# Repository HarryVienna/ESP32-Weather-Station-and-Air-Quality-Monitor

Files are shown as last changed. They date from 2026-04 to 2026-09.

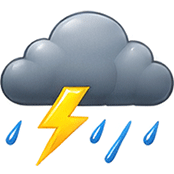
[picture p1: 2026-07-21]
EEZ-Studio-1280x800/images/night_95.png

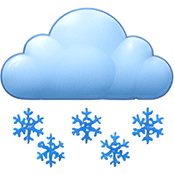
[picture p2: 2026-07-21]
EEZ-Studio-1280x800/images/night_75.png

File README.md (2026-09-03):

# ESP32 Weather Station, Indoor Air Quality & Radiation Monitor

A DIY weather station built from several cooperating ESP32/CubeCell devices: a touchscreen base
station that displays everything, a dedicated radio gateway, and a family of battery-powered
wireless sensor nodes (temperature/humidity, barometric pressure, and radiation) spread around a
house and garden.

🔗 **Read the full story and build log:** [Harald Kreuzer's Blog](https://www.haraldkreuzer.net/en/news/build-guide-esp32-weather-station-and-environmental-monitor)

DSC_2189_mittel

## Overview

The system is split into three tiers:

1. **[`BaseStation/`](BaseStation/README.md)** — an ESP32-P4 with a 10.1" DSI touchscreen. The only
   part you actually interact with: it shows live sensor readings, 24h history charts, a weather
   forecast pulled from the internet, and lets you configure WiFi/location/sensor icons entirely
   from the touchscreen. It also carries its own built-in air quality sensor (SEN66).
2. **[`Sensor-Receiver/`](Sensor-Receiver/)** — an ESP32-S3 that acts as a radio gateway. It listens
   for both LoRa and ESP-NOW packets from the wireless sensor nodes, buffers them, and exposes them
   to the base station over an I2C slave interface. It has its own small OLED status display.
3. **Wireless sensor nodes** — several independent, battery-powered firmwares (see the table below),
   each reading one physical sensor and periodically transmitting a small packet over LoRa or
   ESP-NOW before going back to sleep.

```
 Wireless sensor nodes  --LoRa/ESP-NOW-->  Sensor-Receiver  --I2C-->  BaseStation  <--HTTPS-->  Weather API
 (battery, deep sleep)                     (ESP32-S3)                (ESP32-P4 +
                                                                       touchscreen)
```

## Components

| Folder | Board | Framework | Sensor | Radio | Role |
|---|---|---|---|---|---|
| [`BaseStation`](BaseStation/README.md) | Waveshare ESP32-P4-Module-DEV-KIT | ESP-IDF | SEN66 (built-in) | — | Display, GUI, weather fetch |
| [`Sensor-Receiver`](Sensor-Receiver/) | Heltec WiFi LoRa 32 (ESP32-S3) | ESP-IDF | — | LoRa + ESP-NOW (receiver) | Radio gateway to BaseStation (I2C) |
| [`Sensor-LORA-BME280`](Sensor-LORA-BME280/) | Heltec WiFi LoRa 32 V3/V4 (ESP32-S3) | ESP-IDF | BME280 | LoRa | Temperature/humidity/pressure node |
| [`Sensor-LORA-BME280-HTCC-AB01`](Sensor-LORA-BME280-HTCC-AB01/) | Heltec CubeCell HTCC-AB01 V2 | PlatformIO/Arduino | BME280 | LoRa | Same as above, tiny low-power board |
| [`Sensor-LORA-SHT45`](Sensor-LORA-SHT45/) | Heltec WiFi LoRa 32 V3/V4 (ESP32-S3) | ESP-IDF | SHT45 | LoRa | Temperature/humidity node (no pressure) |
| [`Sensor-LORA-RadiationD`](Sensor-LORA-RadiationD/) | Heltec WiFi LoRa 32 V4 (ESP32-S3) | ESP-IDF | RadiationD-v1.1 Geiger tube | LoRa | Geiger counter node, ULP pulse counting |
| [`Sensor-LORA-RadiationD-HTCC-AB01`](Sensor-LORA-RadiationD-HTCC-AB01/) | Heltec CubeCell HTCC-AB01 V2 | PlatformIO/Arduino | RadiationD-v1.1 Geiger tube | LoRa | Same as above, tiny low-power board |
| [`Sensor-ESP-NOW-BME280`](Sensor-ESP-NOW-BME280/) | generic ESP32 | ESP-IDF | BME280 | ESP-NOW | Temperature/humidity/pressure node (the original, oldest project here) |
| [`EEZ-Studio-1280x800`](EEZ-Studio-1280x800/) | — | [EEZ Studio](https://github.com/eez-open/studio) project | — | — | Design-time source for BaseStation's LVGL touchscreen GUI |

Every LoRa node uses the same link parameters (869.525 MHz, BW125, CR 4/5, sync word `0x1424`), so
the ESP32-based and CubeCell-based variants of the same sensor are interchangeable from
`Sensor-Receiver`'s point of view — it doesn't know or care which MCU sent a packet.

## Shared wire protocol

All sensor nodes and `Sensor-Receiver` share a single `common/packet_format.h` (copied into each
firmware, byte-for-byte identical) that defines the over-the-air packet layout:

- **`message_type_t`** — `PAIRING_REQ` (0), `PAIRING_RESP` (1), `DATA` (2). Pairing is only used on
  the ESP-NOW side, to let a sensor learn the receiver's MAC address/channel on first boot (and
  re-pair automatically if a send ever fails).
- **`sensor_type_t`** — `SENSOR_TYPE_BME280` (1), `SENSOR_TYPE_SHT45` (2), `SENSOR_TYPE_GEIGER` (3),
  `SENSOR_TYPE_CUSTOM` (255).
- **`packet_header_t`** (4 bytes, packed) — `msg_type`, `sensor_nr` (which of the 6 slots this
  sensor occupies), `sensor_type`, `payload_len`.
- **`link_metadata_t`** (11 bytes) — `msg_source` (LoRa/ESP-NOW), `rssi`, `snr`, `timestamp`. Added
  by `Sensor-Receiver` itself; never transmitted over the air.
- One payload struct per sensor type (`bme280_payload_t`, `sht45_payload_t`, `geiger_payload_t`),
  each carrying the measurement plus the sending node's battery voltage.

`BaseStation` reads the same header to know which of its 6 sensor-card slots a packet belongs to
and which struct to cast the payload to.

## Power management

Every wireless node spends nearly all of its life in deep sleep and wakes only to measure and
transmit:

- Temperature/humidity/pressure nodes wake every **10 minutes**, take one reading, transmit, and go
  back to sleep.
- Geiger counter nodes need to accumulate pulses over time rather than take a single instant
  reading, so they wake more often (every 60s on the ESP32 variant, with a rolling average kept in
  RTC memory across wakeups) and keep counting through sleep: the ESP32-based sensor runs a small
  ULP (co-processor) program that counts Geiger pulses even while the main CPU is powered down, so
  no pulses are lost between wakeups. It also uses dynamic CPU frequency scaling and gates the LoRa
  power amplifier on only for the moment of transmission — an iterative optimization that brought
  its average current down from roughly 45 mA to under 30 mA.
- Before sleeping, every ESP32-based node explicitly isolates the radio's SPI pins, the OLED's power
  rail, and unused UART pins to avoid leakage current through them.
- The CubeCell-based nodes (`*-HTCC-AB01`) use the ASR6502's native low-power timer/interrupt
  wake instead of ESP32 deep sleep, since that board has no equivalent RTC/ULP domain.

## Getting started

Each folder is an independent firmware project — `BaseStation`, `Sensor-Receiver` and the ESP32-based
sensor nodes are ESP-IDF projects (`idf.py build`/`flash`); the two `*-HTCC-AB01` nodes are
PlatformIO/Arduino projects (`pio run --target upload`). See
**[`BaseStation/README.md`](BaseStation/README.md)** for the full build/flash walkthrough of the
main display unit, which is the best starting point if you just want to see the system running.

## License

[GPL-3.0](LICENSE)

## Acknowledgments

- [EEZ Studio](https://github.com/eez-open/studio) for the GUI editor/code generator
- [LVGL](https://lvgl.io/) as the graphics library
- Espressif for ESP-IDF and the `esp_lvgl_port`/`esp_lcd_*` driver components
- Heltec for the WiFi LoRa 32 and CubeCell hardware/BSPs

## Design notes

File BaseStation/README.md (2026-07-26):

# ESP32 Weather Station & Indoor Air Quality Monitor — Base Station

*[Deutsch](README_de.md)*

A base station built around the **ESP32-P4** with a 10.1" touchscreen that brings together weather
data from the internet, a built-in air quality sensor, and up to six battery-powered wireless sensors
(LoRa / ESP-NOW) — including a Geiger counter — on a single display.

> This is one component of a larger project — see the
> [repository root README](../README.md) for the full system overview and a photo of the hardware.

## Overview

The overall system consists of three parts:

1. **This base station** (ESP32-P4 + touchscreen) — displays all the data and is the only part you
   actually interact with.
2. A **Sensor Receiver** (ESP32-S3) that collects LoRa and ESP-NOW packets from the wireless sensors
   in the background and forwards them to the base station over I2C.
3. Several **battery-powered wireless sensors** (temperature/humidity, some with barometric pressure,
   plus a Geiger counter), which spend most of their time in deep sleep and only transmit
   periodically.

The base station itself also has a built-in **SEN66** sensor (particulate matter, VOC, NOx, CO₂,
temperature, humidity) and fetches the weather forecast from the internet over WiFi.

## Features

- Live display of all connected sensors (up to 6 wireless sensors + the built-in SEN66)
- 24h history charts with peak bucketing — short spikes (e.g. a brief rise in particulate matter)
  stay visible in the chart instead of disappearing into an average
- Color-coded thresholds for battery voltage, signal strength, particulate matter, VOC, NOx, CO₂ and
  radiation
- Weather forecast from three selectable providers (Open-Meteo, OpenWeatherMap, VisualCrossing) with
  hourly and daily charts
- Geiger counter integration, including its own radiation color scale and 24h history
- Automatic display brightness based on ambient light and presence sensing
- Fully configurable from the touchscreen (WiFi, location/timezone, sensor icons) — no reflashing
  needed for basic setup
- Per-slot offline watchdog: a sensor card's header turns red once that sensor hasn't reported in for
  a while

## Hardware

| Component | Part |
|---|---|
| Board | Waveshare ESP32-P4-Module-DEV-KIT |
| Display | Waveshare 10.1" DSI touch (800×1280, run in 1280×800 landscape) |
| Touch controller | GT911 (capacitive) |
| Built-in air quality sensor | Sensirion SEN66 |
| Ambient light sensor | BH1750 |
| Presence sensor | C4001 (mmWave radar) |
| WiFi | routed through an ESP32-C6 co-processor via esp-hosted (the P4 has no native WiFi radio) |
| Wireless counterpart | Sensor Receiver (ESP32-S3), receives LoRa (SX1262) + ESP-NOW and forwards over I2C |

## Project layout

```
main/
├── main.c              Boot sequence (app_main)
├── config/             Color palette, WiFi/I2C constants
├── display/             DSI panel, backlight, touch
├── i2c/                Shared I2C bus
├── receiver/           I2C polling from the Sensor Receiver, offline watchdog
├── wifi/               WiFi connection, NTP time sync
├── nvs/                Configuration stored in flash
├── weather/            Weather providers (Open-Meteo/OpenWeatherMap/VisualCrossing)
├── lvgl/               Custom LVGL chart widgets (hourly/daily chart)
├── ui/                 Screens generated by EEZ Studio (do not edit by hand)
└── gui/
    ├── sensors/        SEN66 and wireless-sensor display, color scales, 24h charts
    ├── setup/          Setup screen (WiFi, form, keyboard wiring)
    ├── weatherstation/ Starts the background tasks when the main screen loads
    ├── weather/        Weather display
    └── status/         WiFi icon, clock, brightness
```

## Getting started

Requires **ESP-IDF v5.5.4** (other 5.5.x versions are likely compatible but untested).

```powershell
git clone <repo-url>
cd BaseStation
idf.py set-target esp32p4
idf.py build
idf.py -p COMx flash monitor
```

On first boot, the base station shows the setup screen: pick a WiFi network, enter
location/timezone, choose a weather provider (+ API key if needed), and assign an icon to each of
the 6 sensor slots. Everything is stored in NVS and survives a reboot.

> **Note:** `main.c` contains an additional, hardcoded WiFi connection attempt at boot. It exists
> solely for the automatic screenshot task used during development (see `start_screenshot()`) — it's
> not needed for normal operation, since the actual WiFi setup happens through the setup screen.

## Related projects

Part of the same weather station, but with their own firmware/repository:

- **Sensor-Receiver** — ESP32-S3, receives LoRa + ESP-NOW and exposes the data to the base station over I2C
- **Sensor-LORA-BME280** / **Sensor-LORA-SHT45** / **Sensor-LORA-RadiationD** — battery-powered LoRa wireless sensors
- **Sensor-ESP-NOW-BME280** — wireless sensor over ESP-NOW instead of LoRa

## License

[GPL-3.0](LICENSE)

## Acknowledgments

- [EEZ Studio](https://github.com/eez-open/studio) for the GUI editor/code generator
- [LVGL](https://lvgl.io/) as the graphics library
- Espressif for ESP-IDF and the `esp_lvgl_port`/`esp_lcd_*` driver components

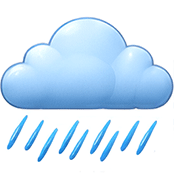
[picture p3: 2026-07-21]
EEZ-Studio-1280x800/images/night_65.png

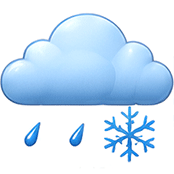
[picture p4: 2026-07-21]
EEZ-Studio-1280x800/images/night_56.png

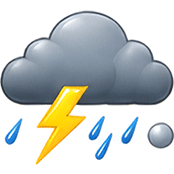
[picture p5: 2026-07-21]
EEZ-Studio-1280x800/images/night_96.png

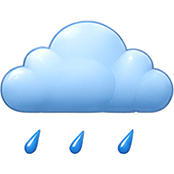
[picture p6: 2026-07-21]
EEZ-Studio-1280x800/images/night_51.png

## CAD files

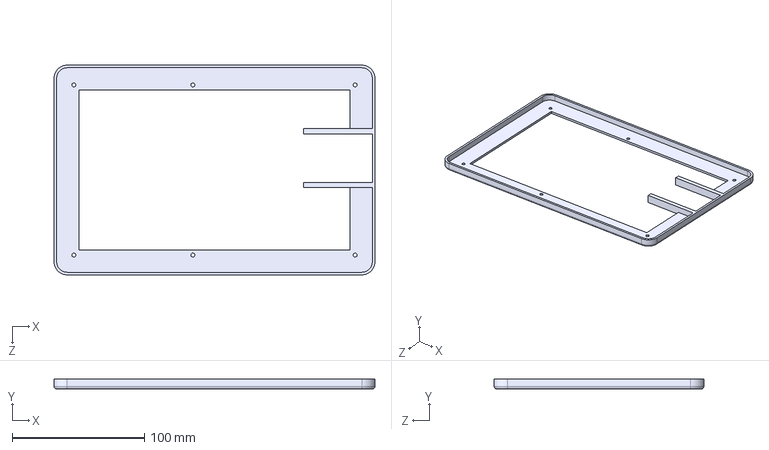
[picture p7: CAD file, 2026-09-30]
SolidWorks/Gehäuse_Guition_Rückwand_Rand.STEP
242.8 x 7.50 x 158.7 mm

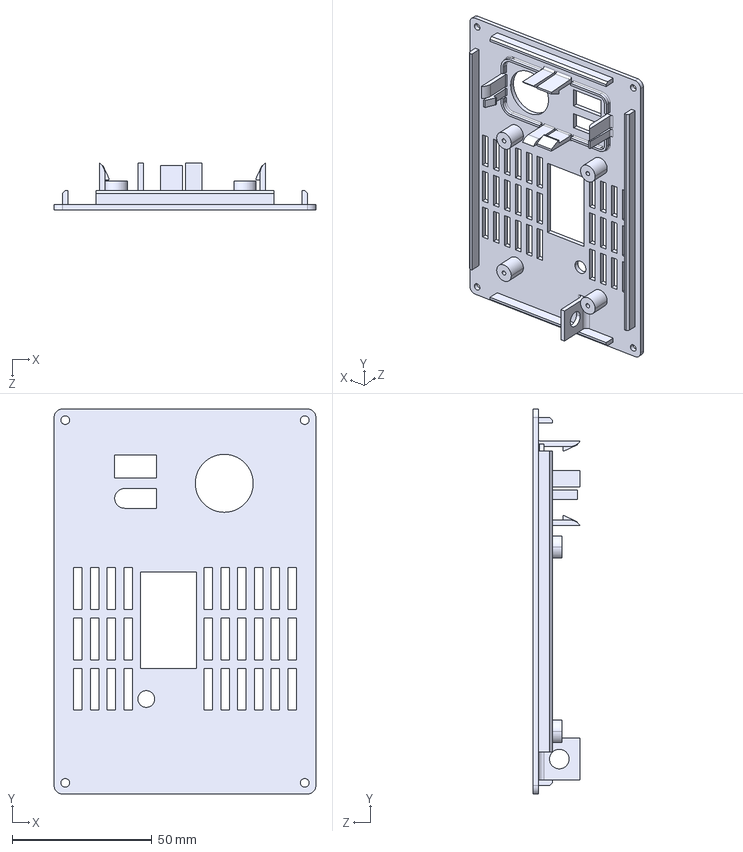
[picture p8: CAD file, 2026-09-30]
SolidWorks/Gehäuse_Guition_Deckel.STEP
93.7 x 137.8 x 17.0 mm

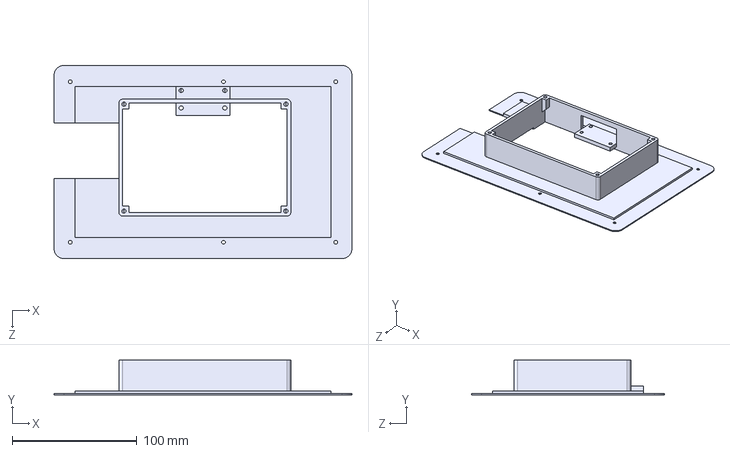
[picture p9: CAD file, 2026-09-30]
SolidWorks/Gehäuse_Guition_Rückwand_Haupt.STEP
238.8 x 28.0 x 154.7 mm

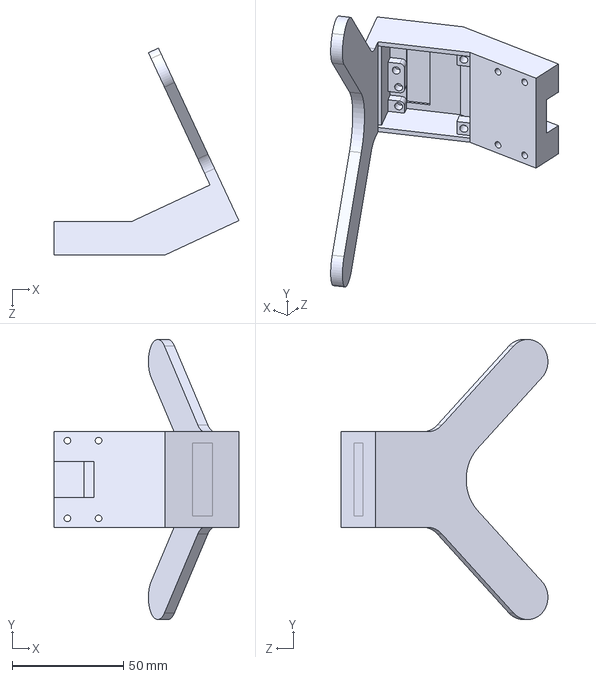
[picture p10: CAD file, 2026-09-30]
SolidWorks/Gehäuse_Guition_Sockel.STEP
83.2 x 126.0 x 93.1 mm

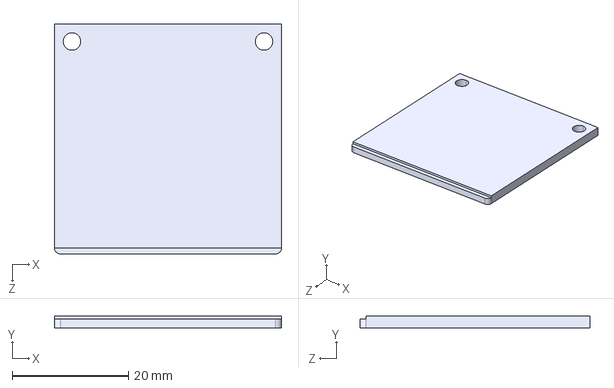
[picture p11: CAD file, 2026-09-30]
SolidWorks/Gehäuse_Guition_Abdeckung.STEP
39.0 x 2.00 x 39.5 mm

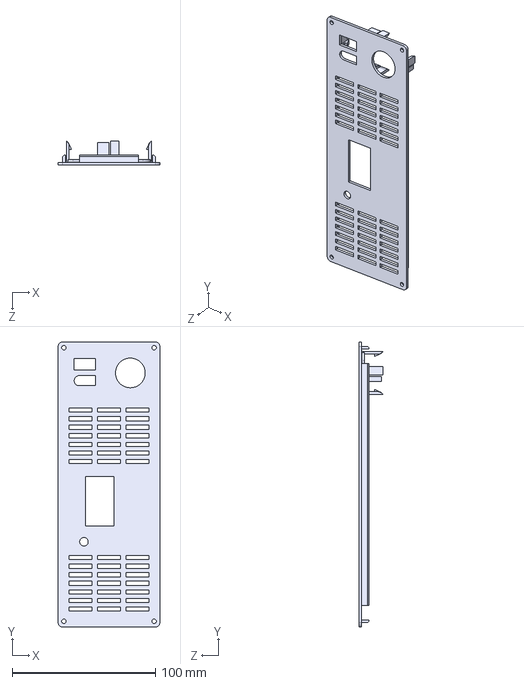
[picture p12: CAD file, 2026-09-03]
SolidWorks/Gehäuse_Waveshare_Deckel.STEP
71.0 x 199.0 x 17.0 mm

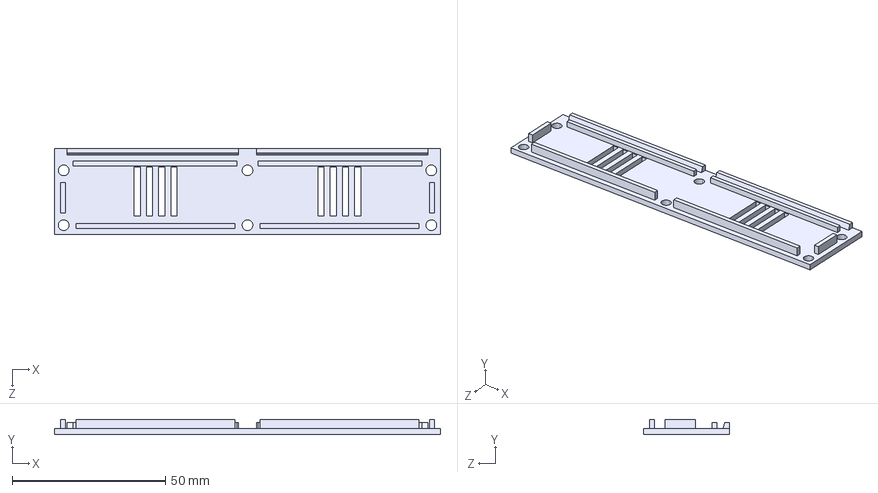
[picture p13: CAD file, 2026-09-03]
SolidWorks/Sensor_Halterung_ESP-NOW_2_Panel_Deckel.STEP
126.0 x 5.00 x 28.0 mm

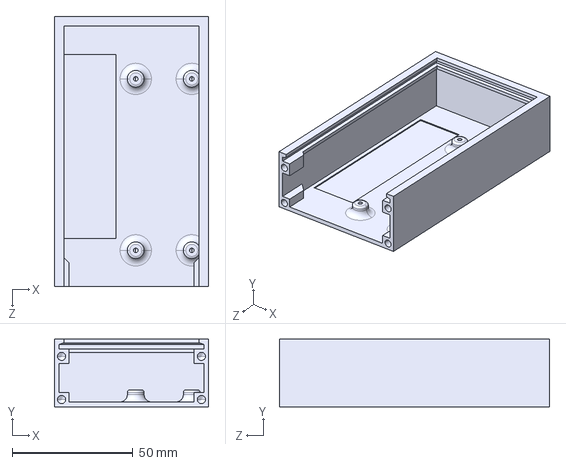
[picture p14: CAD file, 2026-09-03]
SolidWorks/Sensor_Halterung_ESP-NOW_1_Panel.STEP
64.0 x 28.0 x 112.0 mm

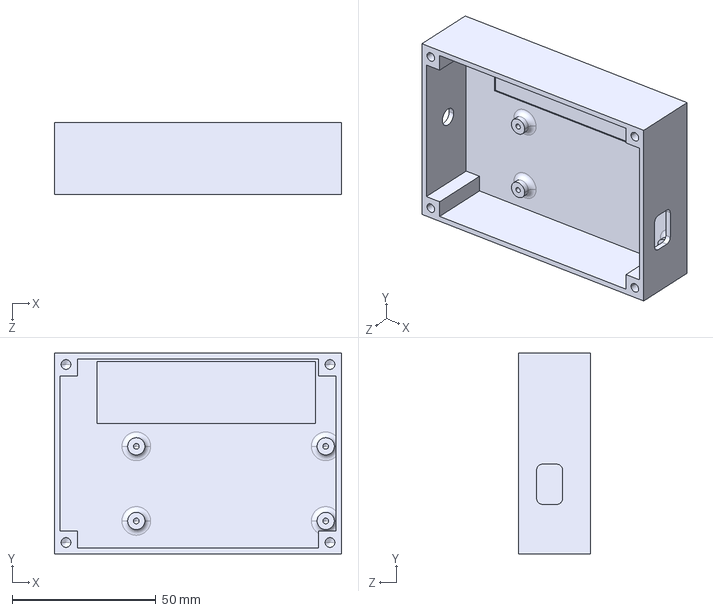
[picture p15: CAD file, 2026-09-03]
SolidWorks/Sensor_Halterung_LoRa.STEP
100.0 x 70.0 x 25.0 mm

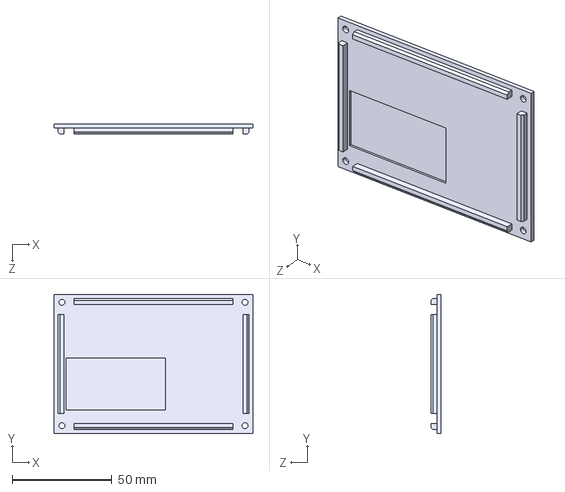
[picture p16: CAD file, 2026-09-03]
SolidWorks/Sensor_Halterung_LoRa_Deckel.STEP
100.0 x 70.0 x 5.00 mm

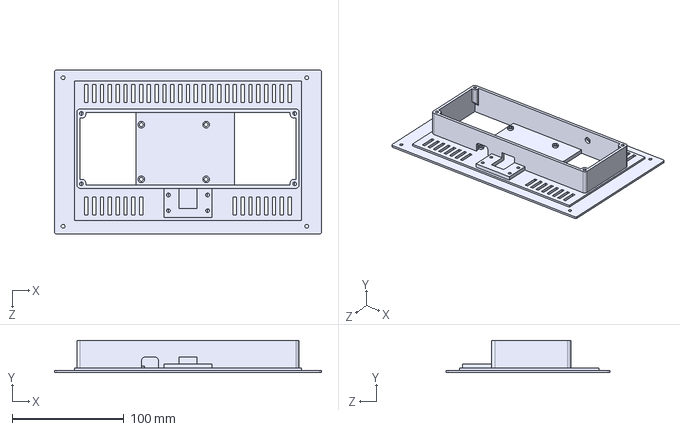
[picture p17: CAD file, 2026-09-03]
SolidWorks/Gehäuse_Waveshare_Rückwand_Haupt.STEP
239.0 x 29.0 x 147.0 mm

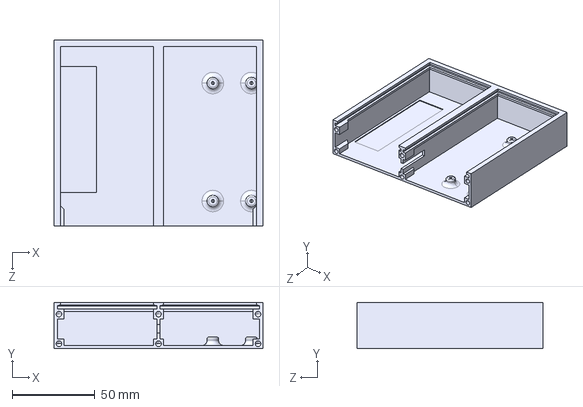
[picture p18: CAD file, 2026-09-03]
SolidWorks/Sensor_Halterung_ESP-NOW_2_Panel.STEP
126.0 x 28.0 x 112.0 mm

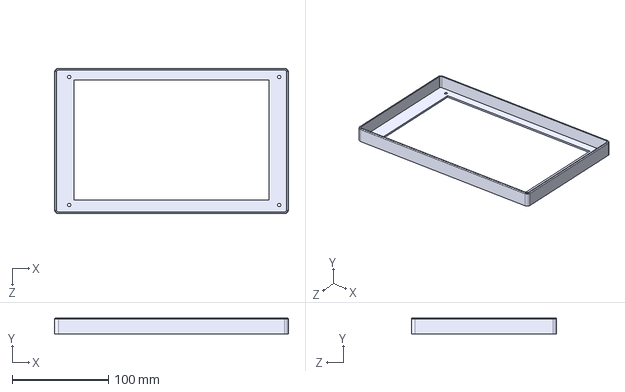
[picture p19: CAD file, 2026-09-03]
SolidWorks/Gehäuse_Waveshare_Rückwand_Rand.STEP
243.0 x 16.5 x 151.0 mm

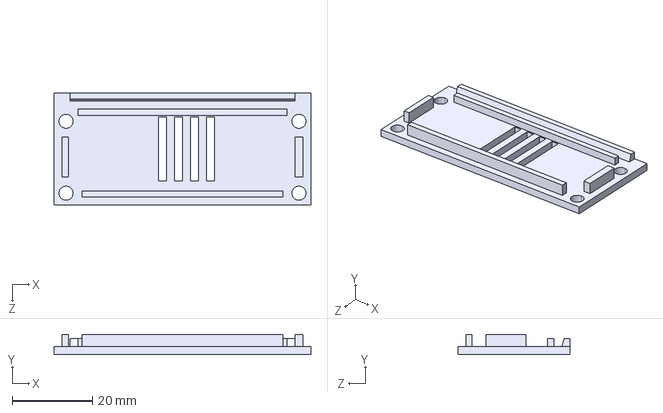
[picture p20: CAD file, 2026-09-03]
SolidWorks/Sensor_Halterung_ESP-NOW_1_Panel_Deckel.STEP
64.0 x 5.00 x 28.0 mm

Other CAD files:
SolidWorks/Gehäuse_Waveshare_Sockel_Deckel.STEP
SolidWorks/Gehäuse_Waveshare_Sockel.STEP
SolidWorks/Gehäuse_Guition_Abdeckung.SLDPRT
SolidWorks/Gehäuse_Guition_Deckel.SLDPRT
SolidWorks/Gehäuse_Guition_Rückwand_Haupt.SLDPRT
SolidWorks/Gehäuse_Guition_Rückwand_Rand.SLDPRT
SolidWorks/Gehäuse_Guition_Sockel.SLDPRT
SolidWorks/Gehäuse_Waveshare_Deckel.SLDPRT
SolidWorks/Gehäuse_Waveshare_Rückwand_Haupt.SLDPRT
SolidWorks/Gehäuse_Waveshare_Rückwand_Rand.SLDPRT
SolidWorks/Gehäuse_Waveshare_Sockel.SLDPRT
SolidWorks/Gehäuse_Waveshare_Sockel_Deckel.SLDPRT
SolidWorks/Sensor_Halterung_ESP-NOW_1_Panel.SLDPRT
SolidWorks/Sensor_Halterung_ESP-NOW_1_Panel_Deckel.SLDPRT
SolidWorks/Sensor_Halterung_ESP-NOW_2_Panel.SLDPRT
SolidWorks/Sensor_Halterung_ESP-NOW_2_Panel_Deckel.SLDPRT
SolidWorks/Sensor_Halterung_LoRa.SLDPRT
SolidWorks/Sensor_Halterung_LoRa_Deckel.SLDPRT

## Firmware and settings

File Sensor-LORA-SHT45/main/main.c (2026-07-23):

/**
 * @file main.c
 * @brief LoRa Sensor Sender — Heltec WiFi LoRa 32 V3 (ESP32-S3 / SX1262)
 *
 * Boot paths:
 *   Reset → config menu on OLED → measure → send → (deep sleep)
 *   Deep sleep wake → load config from NVS → measure → send → (deep sleep)
 */

#include <stdio.h>
#include <string.h>

#include "freertos/FreeRTOS.h"
#include "freertos/task.h"

#include "driver/gpio.h"

#include "esp_adc/adc_oneshot.h"
#include "esp_adc/adc_cali.h"
#include "esp_adc/adc_cali_scheme.h"

#include "esp_sleep.h"
#include "esp_log.h"
#include "nvs_flash.h"

#include "driver/i2c_master.h"

#include "u8g2_esp32_hal.h"
#include "sx1262.h"
#include "sensirion_i2c_hal.h"
#include "sht4x_i2c.h"

#include "../common/packet_format.h"
#include "config.h"

/* ============================================================================
 * Constants
 * ============================================================================ */

#define SLEEP_TIME_SECONDS 600

/* LED */
#define PIN_LED      GPIO_NUM_35

/* Heltec V4 FEM / power pins */
#define PIN_VEXT     GPIO_NUM_36  // Display power (LOW = on)
// #define PIN_VFEM     GPIO_NUM_7   // Amplifier power (HIGH = on)
// #define PIN_PA_CSD   GPIO_NUM_2   // GC1109 chip shutdown (HIGH = enabled)
// #define PIN_PA_CPS   GPIO_NUM_46  // GC1109 RX/TX path (HIGH = high-power TX)

/* Display (SSD1306 128x64) */
#define DISPLAY_SDA  GPIO_NUM_17
#define DISPLAY_SCL  GPIO_NUM_18
#define DISPLAY_RST  GPIO_NUM_21

/* ADC — GPIO37 = ADC_CTRL (HIGH enables voltage divider)
 *         GPIO1  = VBAT_Read = ADC1_CH0
 *         Divider: 390k : 100k = 4.9×                      */
#define ADC_CTRL       GPIO_NUM_37
#define ADC_CHANNEL    ADC_CHANNEL_0
#define ADC_UNIT       ADC_UNIT_1
#define ADC_ATTEN      ADC_ATTEN_DB_2_5
#define ADC_VBAT_R1    390.0f
#define ADC_VBAT_R2    100.0f
#define ADC_VBAT_CALIB (4140.0f / 4037.0f)    // empirical correction (avg 4037 mV, multimeter 4140 mV)
#define ADC_SAMPLES    16                      // average N readings to reduce noise

/* SHT45 I2C bus */
#define I2C_SDA     GPIO_NUM_48
#define I2C_SCL     GPIO_NUM_47

/* UART */
#define UART0_RXD     GPIO_NUM_44
#define UART0_TXD     GPIO_NUM_43

/* LoRa (SX1262 / GC1109) — settings that never change */
#define LORA_FREQUENCY        869525000UL  // 869.525 MHz — G3 band centre
#define LORA_BANDWIDTH        LORA_BW_125
#define LORA_CODING_RATE      LORA_CR_4_5
#define LORA_PREAMBLE_LENGTH  8
#define LORA_PAYLOAD_LENGTH   0
#define LORA_CRC_ON           true
#define LORA_IQ_INVERTED      true
#define LORA_RX_GAIN_BOOSTED  true
#define LORA_SYNC_WORD        0x1424

static const char *TAG = "main";

/* ============================================================================
 * LED
 * ============================================================================ */

static void blink(void) {
    gpio_config_t led_conf = {
        .pin_bit_mask = (1ULL << PIN_LED),
        .mode = GPIO_MODE_OUTPUT,
        .pull_up_en = GPIO_PULLUP_DISABLE,
        .pull_down_en = GPIO_PULLDOWN_DISABLE,
        .intr_type = GPIO_INTR_DISABLE,
    };
    gpio_config(&led_conf);
    gpio_set_level(PIN_LED, 1);
    vTaskDelay(pdMS_TO_TICKS(10));
    gpio_set_level(PIN_LED, 0);
}

/* ============================================================================
 * Board init
 * ============================================================================ */

/**
 * Configure Heltec V3 FEM and optionally the display power rail.
 * Pass enable_display=false on deep-sleep wake to skip VEXT.
 */
static esp_err_t init_heltec_v3(bool enable_display) {
    // Release deep sleep IO hold (no-op on first boot)
    gpio_deep_sleep_hold_dis();

    // FEM pins
    // gpio_config_t io_conf = {
    //     .pin_bit_mask = (1ULL << PIN_VFEM | 1ULL << PIN_PA_CSD | 1ULL << PIN_PA_CPS),
    //     .mode = GPIO_MODE_OUTPUT,
    //     .pull_up_en = GPIO_PULLUP_DISABLE,
    //     .pull_down_en = GPIO_PULLDOWN_DISABLE,
    //     .intr_type = GPIO_INTR_DISABLE,
    // };
    // gpio_config(&io_conf);
    // gpio_set_level(PIN_PA_CSD, 1);
    // gpio_set_level(PIN_PA_CPS, 1);
    // gpio_set_level(PIN_VFEM,   1);

    // VEXT: only on when display is needed (SHT45 runs on permanent 3.3V)
    gpio_config_t vext_conf = {
        .pin_bit_mask = (1ULL << PIN_VEXT),
        .mode = GPIO_MODE_OUTPUT,
        .pull_up_en = GPIO_PULLUP_DISABLE,
        .pull_down_en = GPIO_PULLDOWN_DISABLE,
        .intr_type = GPIO_INTR_DISABLE,
    };
    gpio_config(&vext_conf);
    gpio_set_level(PIN_VEXT, enable_display ? 0 : 1);

    if (enable_display) {
        vTaskDelay(pdMS_TO_TICKS(200));   // VEXT rail stabilisation
    }

    ESP_LOGI(TAG, "Heltec V3 init (display=%s)", enable_display ? "on" : "off");
    return ESP_OK;
}

/* ============================================================================
 * Display
 * ============================================================================ */

static esp_err_t init_display(u8g2_t *u8g2) {
    u8g2_esp32_hal_t hal = U8G2_ESP32_HAL_DEFAULT;
    hal.bus.i2c.sda = DISPLAY_SDA;
    hal.bus.i2c.scl = DISPLAY_SCL;
    hal.reset        = DISPLAY_RST;
    u8g2_esp32_hal_init(hal);

    vTaskDelay(pdMS_TO_TICKS(100));

    u8g2_Setup_ssd1306_i2c_128x64_noname_f(
        u8g2, U8G2_R0,
        u8g2_esp32_i2c_byte_cb,
        u8g2_esp32_gpio_and_delay_cb);
    u8x8_SetI2CAddress(&u8g2->u8x8, 0x3C << 1);

    u8g2_InitDisplay(u8g2);
    u8g2_SetPowerSave(u8g2, 0);

    ESP_LOGI(TAG, "OLED initialized");
    return ESP_OK;
}

/* ============================================================================
 * ADC
 * ============================================================================ */

static esp_err_t get_voltage(uint32_t *voltage) {
    gpio_set_direction(ADC_CTRL, GPIO_MODE_OUTPUT);
    gpio_set_level(ADC_CTRL, 1);
    vTaskDelay(pdMS_TO_TICKS(10));

    adc_oneshot_unit_handle_t adc_handle;
    adc_oneshot_unit_init_cfg_t init_cfg = { .unit_id = ADC_UNIT };
    ESP_ERROR_CHECK(adc_oneshot_new_unit(&init_cfg, &adc_handle));

    adc_oneshot_chan_cfg_t chan_cfg = {
        .atten    = ADC_ATTEN,
        .bitwidth = ADC_BITWIDTH_DEFAULT,
    };
    ESP_ERROR_CHECK(adc_oneshot_config_channel(adc_handle, ADC_CHANNEL, &chan_cfg));

    adc_cali_handle_t cali_handle = NULL;
    adc_cali_curve_fitting_config_t cali_cfg = {
        .unit_id  = ADC_UNIT,
        .atten    = ADC_ATTEN,
        .bitwidth = ADC_BITWIDTH_DEFAULT,
    };
    ESP_ERROR_CHECK(adc_cali_create_scheme_curve_fitting(&cali_cfg, &cali_handle));

    int32_t sum = 0;
    for (int i = 0; i < ADC_SAMPLES; i++) {
        int adc_raw;
        ESP_ERROR_CHECK(adc_oneshot_read(adc_handle, ADC_CHANNEL, &adc_raw));
        int adc_mv;
        ESP_ERROR_CHECK(adc_cali_raw_to_voltage(cali_handle, adc_raw, &adc_mv));
        sum += adc_mv;
    }
    int adc_avg_mv = sum / ADC_SAMPLES;
    ESP_LOGI(TAG, "ADC avg: %d mV (%d samples)", adc_avg_mv, ADC_SAMPLES);

    *voltage = (uint32_t)(adc_avg_mv * (ADC_VBAT_R1 + ADC_VBAT_R2) / ADC_VBAT_R2 * ADC_VBAT_CALIB);
    ESP_LOGI(TAG, "Battery: %lu mV", *voltage);

    gpio_set_level(ADC_CTRL, 0);

    adc_cali_delete_scheme_curve_fitting(cali_handle);
    adc_oneshot_del_unit(adc_handle);
    return ESP_OK;
}

/* ============================================================================
 * LoRa
 * ============================================================================ */

static esp_err_t init_lora(int8_t tx_power, uint8_t sf) {
    if (sx1262_init_bus()   != ESP_OK) return ESP_FAIL;
    if (sx1262_init_radio() != ESP_OK) return ESP_FAIL;

    sx1262_config_t config = {
        .modem_mode       = SX1262_MODEM_LORA,
        .frequency        = LORA_FREQUENCY,
        .tx_power         = tx_power,
        .bandwidth        = LORA_BANDWIDTH,
        .spreading_factor = sf,
        .coding_rate      = LORA_CODING_RATE,
        .iq_inverted      = LORA_IQ_INVERTED,
        .rx_gain_boosted  = LORA_RX_GAIN_BOOSTED,
        .preamble_length  = LORA_PREAMBLE_LENGTH,
        .payload_length   = LORA_PAYLOAD_LENGTH,
        .crc_on           = LORA_CRC_ON,
        .sync_word        = LORA_SYNC_WORD,
    };

    if (sx1262_configure(&config) != ESP_OK) return ESP_FAIL;

    ESP_LOGI(TAG, "LoRa: SF%d BW125 %d dBm @ %lu MHz",
             sf, tx_power, LORA_FREQUENCY / 1000000);
    return ESP_OK;
}

/* ============================================================================
 * Deep sleep
 * ============================================================================ */

static void start_deep_sleep(void) {

    // DEN SPI-GLITCH VERHINDERN
    // NSS Pin hart auf HIGH zwingen
    gpio_set_level(LORA_PIN_NSS, 1); 
    gpio_set_direction(LORA_PIN_NSS, GPIO_MODE_OUTPUT);

    // RESTLICHE LORA PINS ISOLIEREN
    gpio_set_direction(LORA_PIN_SCK, GPIO_MODE_INPUT);  // SCK
    gpio_set_direction(LORA_PIN_MOSI, GPIO_MODE_INPUT); // MOSI
    gpio_set_direction(LORA_PIN_MISO, GPIO_MODE_INPUT); // MISO
    
    gpio_set_direction(LORA_PIN_RST, GPIO_MODE_OUTPUT); // RST
    gpio_set_level(LORA_PIN_RST, 1); // HIGH lassen!

    // VEXT (OLED) hart aus
    gpio_set_direction(PIN_VEXT, GPIO_MODE_OUTPUT);
    gpio_set_level(PIN_VEXT, 1); 

    // I2C-Pins floaten (verhindert Backfeeding durch SHT45)
    gpio_set_direction(I2C_SDA, GPIO_MODE_INPUT);
    gpio_pullup_dis(I2C_SDA);
    gpio_set_direction(I2C_SCL, GPIO_MODE_INPUT);
    gpio_pullup_dis(I2C_SCL);

    // UART / USB-Backfeeding isolieren
    gpio_set_direction(UART0_TXD, GPIO_MODE_INPUT);
    gpio_pullup_dis(UART0_TXD);
    gpio_set_direction(UART0_RXD, GPIO_MODE_INPUT);
    gpio_pullup_dis(UART0_RXD);

    // ALLES EINFRIEREN UND SCHLAFEN
    gpio_deep_sleep_hold_en();
    
    esp_sleep_enable_timer_wakeup(1000000ULL * SLEEP_TIME_SECONDS);

    ESP_LOGI(TAG, "Deep sleep...");
    esp_deep_sleep_start();

}

/* ============================================================================
 * app_main
 * ============================================================================ */

void app_main(void) {
 
    bool show_menu = (esp_reset_reason() != ESP_RST_DEEPSLEEP);

    ESP_LOGI(TAG, "Boot: %s", show_menu ? "reset → config menu" : "timer wake");

    /* NVS — required by config module */
    esp_err_t ret = nvs_flash_init();
    if (ret == ESP_ERR_NVS_NO_FREE_PAGES || ret == ESP_ERR_NVS_NEW_VERSION_FOUND) {
        ESP_LOGW(TAG, "NVS partition wiped, reinitialising");
        ESP_ERROR_CHECK(nvs_flash_erase());
        ESP_ERROR_CHECK(nvs_flash_init());
    }

    /* Load persistent config (fills defaults on first boot) */
    sensor_config_t cfg;
    config_load(&cfg);

    u8g2_t u8g2;

    init_heltec_v3(show_menu);                                                                                                                                                                                                                                                                                                                   

    if (show_menu) {
        ESP_ERROR_CHECK(init_display(&u8g2));
        config_run_menu(&u8g2, &cfg);
        /* config_run_menu saves to NVS before returning */
    }

    /* ── Measure ── */

    uint32_t voltage = 0;
    get_voltage(&voltage);

    i2c_master_bus_config_t bus_cfg = {
        .i2c_port             = I2C_NUM_0,
        .sda_io_num           = I2C_SDA,
        .scl_io_num           = I2C_SCL,
        .clk_source           = I2C_CLK_SRC_DEFAULT,
        .glitch_ignore_cnt    = 7,
        .flags.enable_internal_pullup = true,
    };
    i2c_master_bus_handle_t i2c_bus;
    ESP_ERROR_CHECK(i2c_new_master_bus(&bus_cfg, &i2c_bus));

    sensirion_i2c_hal_init(i2c_bus);
    sht4x_init(SHT45_I2C_ADDR_44);

    // SHT45 braucht nach Power-on ~1ms; Soft-Reset für sauberen Zustand
    sht4x_soft_reset();
    sensirion_i2c_hal_sleep_usec(1000);

    // --------------------------------------- 
    // uint32_t serial_number = 0;
    // int16_t serial_err = sht4x_serial_number(&serial_number);
    // if (serial_err != 0) {
    //     ESP_LOGE(TAG, "SHT45 serial number read failed: %d", serial_err);
    // } else {
    //     ESP_LOGI(TAG, "SHT45 serial number: 0x%08lX", serial_number);
    // }

    // int32_t heater_temp_milli = 0;
    // int32_t heater_humi_milli = 0;
    // int16_t heater_err = sht4x_activate_highest_heater_power_long(&heater_temp_milli, &heater_humi_milli);
    // if (heater_err != 0) {
    //     ESP_LOGE(TAG, "SHT45 heater measurement failed: %d", heater_err);
    // } else {
    //     ESP_LOGI(TAG, "SHT45 heater: %.2f°C / %.2f%%RH",
    //              heater_temp_milli / 1000.0f, heater_humi_milli / 1000.0f);
    // }

    // // Test-Stopp: hier anhalten, kein Messen/Senden/Deep-Sleep
    // sensirion_i2c_hal_free();
    // i2c_del_master_bus(i2c_bus);
    // ESP_LOGI(TAG, "Test done, halting.");
    // while (1) {
    //     vTaskDelay(pdMS_TO_TICKS(1000));
    // }
    // ---------------------------------------

    int32_t temp_milli = 0;
    int32_t humi_milli = 0;
    // High-precision Messung dauert ~8.2ms intern (Single-Shot, danach idle)
    int16_t sht_err = sht4x_measure_high_precision(&temp_milli, &humi_milli);
    if (sht_err != 0) {
        ESP_LOGE(TAG, "SHT45 measure failed: %d", sht_err);
    } else {
        ESP_LOGI(TAG, "SHT45: %.2f°C / %.2f%%RH",
                 temp_milli / 1000.0f, humi_milli / 1000.0f);
    }

    // I2C-Ressourcen freigeben bevor Deep Sleep
    sensirion_i2c_hal_free();
    i2c_del_master_bus(i2c_bus);

    /* ── Send ── */
    ESP_ERROR_CHECK(init_lora(cfg.tx_power, cfg.spreading_factor));

    lora_sensor_packet_t packet;
    memset(&packet, 0, sizeof(packet));
    packet.header.msg_type    = DATA;
    packet.header.sensor_nr   = cfg.sensor_nr;
    packet.header.sensor_type = SENSOR_TYPE_SHT45;

    sht45_payload_t sht45_payload = {
        .voltage     = voltage,
        .temperature = temp_milli / 1000.0f,
        .humidity    = humi_milli / 1000.0f,
    };
    memcpy(packet.payload, &sht45_payload, sizeof(sht45_payload_t));
    packet.header.payload_len = sizeof(sht45_payload_t);

    uint32_t total_len = sizeof(packet_header_t) + packet.header.payload_len;
    ESP_LOGI(TAG, "TX: sensor=%d len=%lu", cfg.sensor_nr, total_len);

    esp_err_t send_err = sx1262_send((uint8_t *)&packet, total_len);

    if (send_err == ESP_OK) {
        ESP_LOGI(TAG, "LoRa send OK");
    } else {
        ESP_LOGE(TAG, "LoRa send failed: %s", esp_err_to_name(send_err));
    }
    sx1262_sleep();

    blink();

    start_deep_sleep();
}

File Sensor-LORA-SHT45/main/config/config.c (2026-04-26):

#include "config.h"

#include "freertos/FreeRTOS.h"
#include "freertos/task.h"
#include "freertos/queue.h"

#include "nvs_flash.h"
#include "nvs.h"
#include "driver/gpio.h"
#include "esp_log.h"
#include "button.h"

#include <string.h>

static const char *TAG = "config";

#define NVS_NAMESPACE   "sensor_cfg"
#define NVS_KEY_NR      "sensor_nr"
#define NVS_KEY_POWER   "tx_power"
#define NVS_KEY_SF      "sf"

#define BUTTON_GPIO     GPIO_NUM_0

#define SENSOR_NR_MIN   0
#define SENSOR_NR_MAX   15
#define TX_POWER_MIN    (-9)
#define TX_POWER_MAX    22
#define SF_MIN          7
#define SF_MAX          12

/* ============================================================================
 * NVS
 * ============================================================================ */

esp_err_t config_load(sensor_config_t *cfg) {
    cfg->sensor_nr        = CONFIG_DEFAULT_SENSOR_NR;
    cfg->tx_power         = CONFIG_DEFAULT_TX_POWER;
    cfg->spreading_factor = CONFIG_DEFAULT_SF;

    nvs_handle_t h;
    esp_err_t ret = nvs_open(NVS_NAMESPACE, NVS_READONLY, &h);
    if (ret != ESP_OK) {
        ESP_LOGI(TAG, "No saved config, using defaults (nr=%d pwr=%d sf=%d)",
                 cfg->sensor_nr, cfg->tx_power, cfg->spreading_factor);
        return ESP_OK;
    }

    uint8_t nr, sf;
    int8_t  pwr;
    if (nvs_get_u8(h, NVS_KEY_NR,    &nr)  == ESP_OK) cfg->sensor_nr        = nr;
    if (nvs_get_i8(h, NVS_KEY_POWER, &pwr) == ESP_OK) cfg->tx_power         = pwr;
    if (nvs_get_u8(h, NVS_KEY_SF,    &sf)  == ESP_OK) cfg->spreading_factor = sf;

    nvs_close(h);
    ESP_LOGI(TAG, "Config loaded: sensor_nr=%d tx_power=%d sf=%d",
             cfg->sensor_nr, cfg->tx_power, cfg->spreading_factor);
    return ESP_OK;
}

esp_err_t config_save(const sensor_config_t *cfg) {
    nvs_handle_t h;
    ESP_ERROR_CHECK(nvs_open(NVS_NAMESPACE, NVS_READWRITE, &h));
    ESP_ERROR_CHECK(nvs_set_u8(h, NVS_KEY_NR,    cfg->sensor_nr));
    ESP_ERROR_CHECK(nvs_set_i8(h, NVS_KEY_POWER, cfg->tx_power));
    ESP_ERROR_CHECK(nvs_set_u8(h, NVS_KEY_SF,    cfg->spreading_factor));
    ESP_ERROR_CHECK(nvs_commit(h));
    nvs_close(h);
    ESP_LOGI(TAG, "Config saved: sensor_nr=%d tx_power=%d sf=%d",
             cfg->sensor_nr, cfg->tx_power, cfg->spreading_factor);
    return ESP_OK;
}

/* ============================================================================
 * Menu display
 * ============================================================================ */

typedef enum {
    ITEM_SENSOR_NR = 0,
    ITEM_TX_POWER,
    ITEM_SF,
    ITEM_SAVE,
    ITEM_COUNT
} menu_item_t;

static void draw_value(u8g2_t *u8g2, int y, const char *label, const char *value,
                       bool is_active, bool is_editing) {
    if (is_active && !is_editing) {
        u8g2_DrawStr(u8g2, 0, y, ">");
    }
    u8g2_DrawStr(u8g2, 9, y, label);

    int vw = u8g2_GetStrWidth(u8g2, value);
    int vx = 125 - vw;

    if (is_active && is_editing) {
        u8g2_DrawBox(u8g2, vx - 2, y - 10, vw + 4, 12);
        u8g2_SetDrawColor(u8g2, 0);
        u8g2_DrawStr(u8g2, vx, y, value);
        u8g2_SetDrawColor(u8g2, 1);
    } else {
        u8g2_DrawStr(u8g2, vx, y, value);
    }
}

static void menu_draw(u8g2_t *u8g2, menu_item_t item, bool editing,
                      const sensor_config_t *cfg) {
    char buf[16];

    u8g2_ClearBuffer(u8g2);
    u8g2_SetFont(u8g2, u8g2_font_6x10_tr);

    // Title
    u8g2_DrawStr(u8g2, 37, 10, "CONFIG");
    u8g2_DrawHLine(u8g2, 0, 12, 128);

    // Sensor Nr  (y=23)
    snprintf(buf, sizeof(buf), "%d", cfg->sensor_nr);
    draw_value(u8g2, 23, "Sensor Nr:", buf,
               item == ITEM_SENSOR_NR, editing && item == ITEM_SENSOR_NR);

    // TX Power  (y=34)
    snprintf(buf, sizeof(buf), "%d dBm", cfg->tx_power);
    draw_value(u8g2, 34, "TX Power:", buf,
               item == ITEM_TX_POWER, editing && item == ITEM_TX_POWER);

    // Spreading Factor  (y=45)
    snprintf(buf, sizeof(buf), "SF%d", cfg->spreading_factor);
    draw_value(u8g2, 45, "SF:", buf,
               item == ITEM_SF, editing && item == ITEM_SF);

    // Save button (centered, highlighted when active)
    const char *save_str = "[ SAVE ]";
    int sw = u8g2_GetStrWidth(u8g2, save_str);
    int sx = (128 - sw) / 2;
    if (item == ITEM_SAVE) {
        u8g2_DrawBox(u8g2, sx - 3, 52, sw + 6, 12);
        u8g2_SetDrawColor(u8g2, 0);
        u8g2_DrawStr(u8g2, sx, 62, save_str);
        u8g2_SetDrawColor(u8g2, 1);
    } else {
        u8g2_DrawStr(u8g2, sx, 62, save_str);
    }

    u8g2_SendBuffer(u8g2);
}

/* ============================================================================
 * Button handling
 * ============================================================================ */

typedef enum { EVT_SHORT, EVT_LONG } btn_evt_t;

static QueueHandle_t s_btn_queue;

static void btn_callback(button_press_type_t type) {
    btn_evt_t evt = (type == BUTTON_PRESS_SHORT) ? EVT_SHORT : EVT_LONG;
    xQueueSend(s_btn_queue, &evt, 0);
}
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

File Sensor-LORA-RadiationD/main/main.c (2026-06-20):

/**
 * @file main.c
 * @brief LoRa Geigerzähler Sender — Heltec WiFi LoRa 32 V4 (ESP32-S3 / SX1262)
 *
 * Architektur: Deep Sleep + ULP-FSM für verlustfreie Impulszählung.
 *
 * Normalbetrieb  → Deep Sleep
 * ULP läuft in einer permanenten Endschleife (Dauerlauf)
 * und zählt Impulse auf GPIO4 im Unter-Mikrosekunden-Takt.
 * RTC-Timer weckt alle 60s für LoRa-TX.
 * GPIO0 (Taste) weckt für Display-Modus.
 *
 * Timer-Wakeup   → ULP edge_count lesen → Gleitenden 60-Minuten-Durchschnitt 
 * berechnen → LoRa TX → Sleep.
 * Button-Wakeup  → Display an, Live-Werte aus dem RTC-Speicher anzeigen.
 * Nach 5 Sekunden Timeout → Sleep.
 *
 * Geiger-Sensor (RadiationD-v1.1) auf GPIO4 (RTC-IO4).
 */

#include <stdio.h>
#include <string.h>

#include "freertos/FreeRTOS.h"
#include "freertos/task.h"

#include "driver/gpio.h"
#include "driver/rtc_io.h"

#include "esp_adc/adc_oneshot.h"
#include "esp_adc/adc_cali.h"
#include "esp_adc/adc_cali_scheme.h"

#include "esp_log.h"
#include "esp_pm.h"
#include "esp_sleep.h"
#include "nvs_flash.h"

#include "ulp.h"
#include "ulp_main.h"   /* Auto-generiert aus pulse_cnt.S */

#include "u8g2_esp32_hal.h"
#include "sx1262.h"

#include "../common/packet_format.h"
#include "config.h"

/* ============================================================================
 * Konstanten
 * ============================================================================ */

#define TX_INTERVAL_SECONDS    60
#define ROLLING_WINDOW_MINUTES 60

/* --- Board-Pins --- */
#define PIN_LED      GPIO_NUM_35
#define PIN_VEXT     GPIO_NUM_36   /* Display-Stromversorgung (LOW = an) */
#define PIN_VFEM     GPIO_NUM_7    /* RF-Verstärker-Versorgung (HIGH = an) */
#define PIN_PA_CSD   GPIO_NUM_2    /* GC1109 Chip-Enable (HIGH = aktiv) */
#define PIN_PA_CPS   GPIO_NUM_46   /* GC1109 RX/TX-Pfad (HIGH = High-Power TX) */

#define DISPLAY_SDA  GPIO_NUM_17
#define DISPLAY_SCL  GPIO_NUM_18
#define DISPLAY_RST  GPIO_NUM_21

/* GPIO0: Deep-Sleep-Wakeup (Taste) und Config-Menü (Boot-Taste) */
#define BUTTON_GPIO  GPIO_NUM_0

/* ADC */
#define ADC_CTRL       GPIO_NUM_37
#define ADC_CHANNEL    ADC_CHANNEL_0
#define ADC_UNIT       ADC_UNIT_1
#define ADC_ATTEN      ADC_ATTEN_DB_2_5
#define ADC_VBAT_R1    390.0f
#define ADC_VBAT_R2    100.0f
#define ADC_VBAT_CALIB (4140.0f / 4037.0f)
#define ADC_SAMPLES    16

/* Geigerzähler */
#define PIN_GEIGER                   GPIO_NUM_4
#define GEIGER_CONVERSION_FACTOR     153.8f

/* LoRa */
#define LORA_FREQUENCY        869525000UL
#define LORA_BANDWIDTH        LORA_BW_125
#define LORA_CODING_RATE      LORA_CR_4_5
#define LORA_PREAMBLE_LENGTH  8
#define LORA_PAYLOAD_LENGTH   0
#define LORA_CRC_ON           true
#define LORA_IQ_INVERTED      true
#define LORA_RX_GAIN_BOOSTED  true
#define LORA_SYNC_WORD        0x1424

static const char *TAG = "main";

/* ============================================================================
 * RTC-Speicher (überlebt Deep Sleep)
 * ============================================================================ */

static RTC_DATA_ATTR sensor_config_t  rtc_cfg;
static RTC_DATA_ATTR bool             rtc_cfg_valid  = false;
static RTC_DATA_ATTR uint32_t         rtc_voltage_mv = 3700;
static RTC_DATA_ATTR float            rtc_last_cpm   = 0.0f;
static RTC_DATA_ATTR float            rtc_last_usvh  = 0.0f;

/* Gleitendes Fenster im RTC-Speicher */
static RTC_DATA_ATTR uint32_t         rtc_history[ROLLING_WINDOW_MINUTES];
static RTC_DATA_ATTR int              rtc_history_idx = 0;
static RTC_DATA_ATTR int              rtc_minutes_elapsed = 0;
static RTC_DATA_ATTR uint32_t         rtc_total_counts = 0;

/* ============================================================================
 * ULP-Binär
 * ============================================================================ */

extern const uint8_t ulp_main_bin_start[] asm("_binary_ulp_main_bin_start");
extern const uint8_t ulp_main_bin_end[]   asm("_binary_ulp_main_bin_end");

/* ============================================================================
 * Hilfsfunktionen & Peripherie-Init
 * ============================================================================ */

static void blink(void) {
    gpio_config_t led_conf = {
        .pin_bit_mask = (1ULL << PIN_LED),
        .mode         = GPIO_MODE_OUTPUT,
        .pull_up_en   = GPIO_PULLUP_DISABLE,
        .pull_down_en = GPIO_PULLDOWN_DISABLE,
        .intr_type    = GPIO_INTR_DISABLE,
    };
    gpio_config(&led_conf);
    gpio_set_level(PIN_LED, 1);
    vTaskDelay(pdMS_TO_TICKS(10));
    gpio_set_level(PIN_LED, 0);
}

static void init_heltec_v4(bool display_power) {
    gpio_config_t io_conf = {
        .pin_bit_mask = (1ULL << PIN_VEXT | 1ULL << PIN_VFEM |
                         1ULL << PIN_PA_CSD | 1ULL << PIN_PA_CPS),
        .mode         = GPIO_MODE_OUTPUT,
        .pull_up_en   = GPIO_PULLUP_DISABLE,
        .pull_down_en = GPIO_PULLDOWN_DISABLE,
        .intr_type    = GPIO_INTR_DISABLE,
    };
    gpio_config(&io_conf);

    gpio_set_level(PIN_VEXT,   display_power ? 0 : 1);  /* 0 = an, 1 = aus */
    gpio_set_level(PIN_PA_CSD, 0);
    gpio_set_level(PIN_PA_CPS, 0);
    gpio_set_level(PIN_VFEM,   0);

    if (display_power) {
        vTaskDelay(pdMS_TO_TICKS(200));
    }
}

static void rf_amp_enable(void) {
    gpio_set_level(PIN_PA_CSD, 1);
    gpio_set_level(PIN_PA_CPS, 1);
    gpio_set_level(PIN_VFEM,   1);
    vTaskDelay(pdMS_TO_TICKS(200));
}

static void rf_amp_disable(void) {
    gpio_set_level(PIN_VFEM,   0);
    gpio_set_level(PIN_PA_CSD, 0);
    gpio_set_level(PIN_PA_CPS, 0);
}

/* ============================================================================
 * Display
 * ============================================================================ */

static esp_err_t init_display(u8g2_t *u8g2) {
    u8g2_esp32_hal_t hal = U8G2_ESP32_HAL_DEFAULT;
    hal.bus.i2c.sda = DISPLAY_SDA;
    hal.bus.i2c.scl = DISPLAY_SCL;
    hal.reset        = DISPLAY_RST;
    u8g2_esp32_hal_init(hal);
    vTaskDelay(pdMS_TO_TICKS(100));

    u8g2_Setup_ssd1306_i2c_128x64_noname_f(
        u8g2, U8G2_R0,
        u8g2_esp32_i2c_byte_cb,
        u8g2_esp32_gpio_and_delay_cb);
    u8x8_SetI2CAddress(&u8g2->u8x8, 0x3C << 1);
    u8g2_InitDisplay(u8g2);
    u8g2_SetPowerSave(u8g2, 0);

    return ESP_OK;
}
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

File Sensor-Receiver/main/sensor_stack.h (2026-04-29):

#ifndef SENSOR_STACK_H
#define SENSOR_STACK_H

#include <stdint.h>
#include <stdbool.h>
#include "freertos/FreeRTOS.h"

/* ============================================================================
 * Common packet format - shared with sender project
 * Copy common/packet_format.h into your sender project as well
 * ============================================================================ */
#include "../common/packet_format.h"

/* ============================================================================
 * Payload format enum (P4-only, not needed by sender)
 * ============================================================================ */

typedef enum {
    SENSOR_PAYLOAD_NONE    = 0,   // No payload (e.g., beacon)
    SENSOR_PAYLOAD_BME280  = 1,   // temp(4) + hum(4) + press(4) = 12 bytes
    SENSOR_PAYLOAD_HDC1080 = 2,   // temp(4) + hum(4) = 8 bytes
    SENSOR_PAYLOAD_DHT22   = 3,   // temp(4) + hum(4) = 8 bytes
    SENSOR_PAYLOAD_WIND    = 4,   // speed(4) + dir(4) = 8 bytes
    SENSOR_PAYLOAD_RAIN    = 5,   // amount(4) = 4 bytes
    SENSOR_PAYLOAD_LIGHT   = 6,   // lux(4) = 4 bytes
    SENSOR_PAYLOAD_CUSTOM  = 255, // Variable format, defined by sensor_type
} sensor_payload_format_t;

/* ============================================================================
 * Sensor Stack: one slot per sensor, latest value wins
 * New data from the same sensor overwrites the previous unread value.
 * Reading a slot (pop) marks it as consumed.
 * ============================================================================ */

#define MAX_SENSORS           64   // Maximum number of distinct sensors
#define I2C_SLAVE_ADDR        0x38
#define I2C_CLOCK_KHZ         400

/* I2C Register Map for P4 master readout */
#define I2C_REG_COUNT         0x00    // Number of available packets (1 byte)
#define I2C_REG_PACKET_READ   0x01    // Read & consume next packet (variable length)
#define I2C_REG_RESET_DROP    0x23    // Write 0x01 to reset dropped counter
#define I2C_REG_STATS_RECV    0x24    // Total packets received (4 bytes, uint32_t)
#define I2C_REG_STATS_OVERWR  0x28    // Total overwritten packets (4 bytes, uint32_t)

/* I2C packet size constants */
#define I2C_MIN_PACKET_SIZE   17  // header(4) + metadata(11) + min_payload(2)
#define I2C_MAX_PACKET_SIZE   79  // header(4) + metadata(11) + max_payload(64)

typedef struct {
    sensor_packet_t packet;
    bool valid;                     // true = unread data available
} sensor_slot_t;

typedef struct {
    sensor_slot_t slots[MAX_SENSORS];  // indexed directly by sensor_nr
    uint8_t count;                     // number of slots with unread data
    uint32_t total_received;
    uint32_t total_overwritten;        // replaced unread data (same sensor updated)
} sensor_stack_t;

/* ============================================================================
 * API Functions
 * ============================================================================ */

/**
 * @brief Initialize the sensor stack
 * @return ESP_OK on success
 */
esp_err_t sensor_stack_init(void);

/**
 * @brief Push a sensor packet into the stack.
 *        If a slot for this sensor_nr already exists, it is overwritten.
 *        If no slot exists yet, a free slot is allocated.
 * @param packet Pointer to the sensor packet (must have valid header + payload)
 * @param source SENSOR_SOURCE_LORA or SENSOR_SOURCE_ESPNOW
 * @return ESP_OK on success, ESP_ERR_NO_MEM if MAX_SENSORS limit reached
 */
esp_err_t sensor_stack_push(const sensor_packet_t *packet, sensor_source_t source);

/**
 * @brief Read and consume the next available packet.
 *        After this call the slot is marked free (for a new sensor if needed).
 * @param packet Output buffer for the packet
 * @return ESP_OK if a packet was read, ESP_ERR_NOT_FOUND if stack empty
 */
esp_err_t sensor_stack_pop(sensor_packet_t *packet);

/**
 * @brief Get the number of sensors with unread data
 * @return Number of valid (unread) slots
 */
uint8_t sensor_stack_count(void);

/**
 * @brief Get statistics
 * @param received    Output: total packets received
 * @param overwritten Output: packets that replaced unread data (same sensor updated)
 */
void sensor_stack_stats(uint32_t *received, uint32_t *overwritten);

/**
 * @brief Reset the dropped and overwritten counters
 */
void sensor_stack_reset_dropped(void);

#endif /* SENSOR_STACK_H */

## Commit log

2026-04-26 Change pin names
2026-04-28 Revert "Add Screensaver"
    This reverts commit 122933ca8f5fc4b9dde445e3bd01e5de562c9c0f.
    [display.c, display.h]
2026-04-28 Toggel Display with Button
2026-04-29 Add I2C
2026-04-29 Move i2c code
2026-07-05 GUI improvements, Sensor watchdog
2026-07-21 New icons, GUI changes
    [partitions.csv]
2026-07-27 Add OTA update
    [partitions.csv]
2026-08-09 Receiver Upgrade ESP-IDF 6.0.2 & OTA
    [partitions.csv]
2026-08-21 Prepare Guition JC8012P4A1C-I-W-Y Display. Improve network code. Bugfixes
    [display.h, display_guition.c, display_waveshare.c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]
2026-08-22 MInor I2C change
2026-09-03 Add enclosure files
    [Gehäuse_Waveshare_Deckel.SLDPRT, Gehäuse_Waveshare_Deckel.STEP, Gehäuse_Waveshare_Rückwand_Haupt.SLDPRT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]
2026-09-14 Fix for random crash (hopefully)
    [sensor_sen66_task.c]
2026-09-30 Add case for Guition JC8012P4A1C display
    [Gehäuse_Guition_Abdeckung.SLDPRT, Gehäuse_Guition_Abdeckung.STEP, Gehäuse_Guition_Deckel.SLDPRT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]
2026-10-28 Forgot Waveshare I2C config
